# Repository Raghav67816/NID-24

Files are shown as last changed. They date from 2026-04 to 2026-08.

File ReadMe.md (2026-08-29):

# NID-24

NID-24 is a EMG based Humand Device Interface system that allows users to experience unique ways to interact with computers.

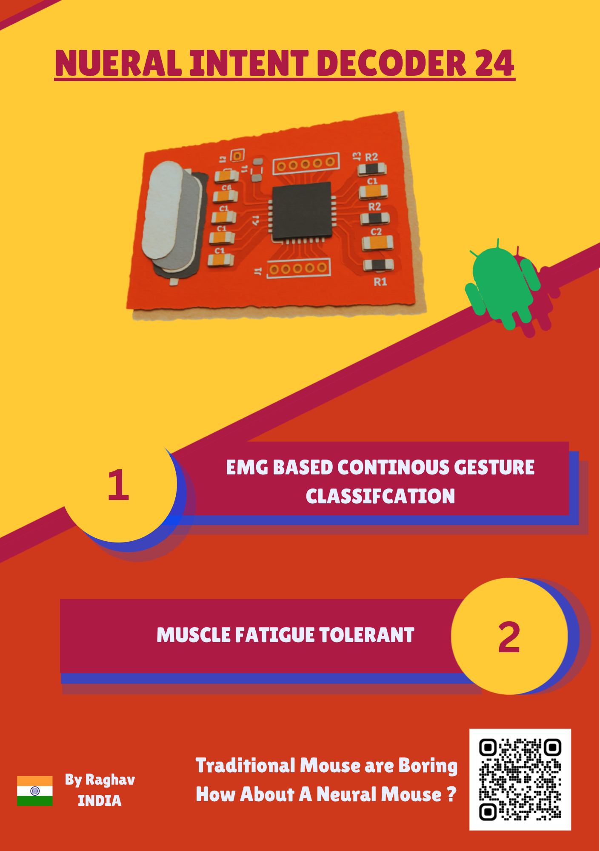
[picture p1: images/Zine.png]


Demo Link - [NID-24 Demo](https://youtu.be/rfTXhZ9J3WQ)

This project allows users to use their hand as mouse. Based on ADS1293 and state-of-the-art software architecture, it continously classifies intent and executes it via bluetooth.

## Why I am building NID-24 ?
Biotech is super awesome, it sits at the intersection of biology and technology. Most of my projects that I made are inspired by sci-fi movies. So, this one is special one from Iron Man 3.

Also, I have some experience in working with EEG, however, I don't have access to a specialised lab, I am building this surface EMG (sEMG) system.

**The second phase of this project will involve finding relevant techniques for making robust EMG system which will can tolerate muscle fatigue and deliver similar performance.**

## Features

 - Analysis Software - Watch and Record Signals In Real Time.

  - ADS1293 Simulator Android App - Don't have the hardware ? Don't worry we have an android app to simulate the hardware readings.

  - Controller Board - Consists of the main MCU Teensy 4.0 for on-board processing, 3 push buttons for menu control, a bluetooth module for data transfer and an OLED 0.96 Inch display

  - ADS1293 based Board - ADS1293 the heart of this project sits at the center of this PCB allowing easy interfacing of chip with the system.

## Directory Structure
- nsys - Analysis Software
- controller_board - The Controller Board
- ads1293_board - The ADS1293 based board
- SignalsSimulator - The Android App (It has it's own readme. Follow instructions to use and install)

## Analysis Software 

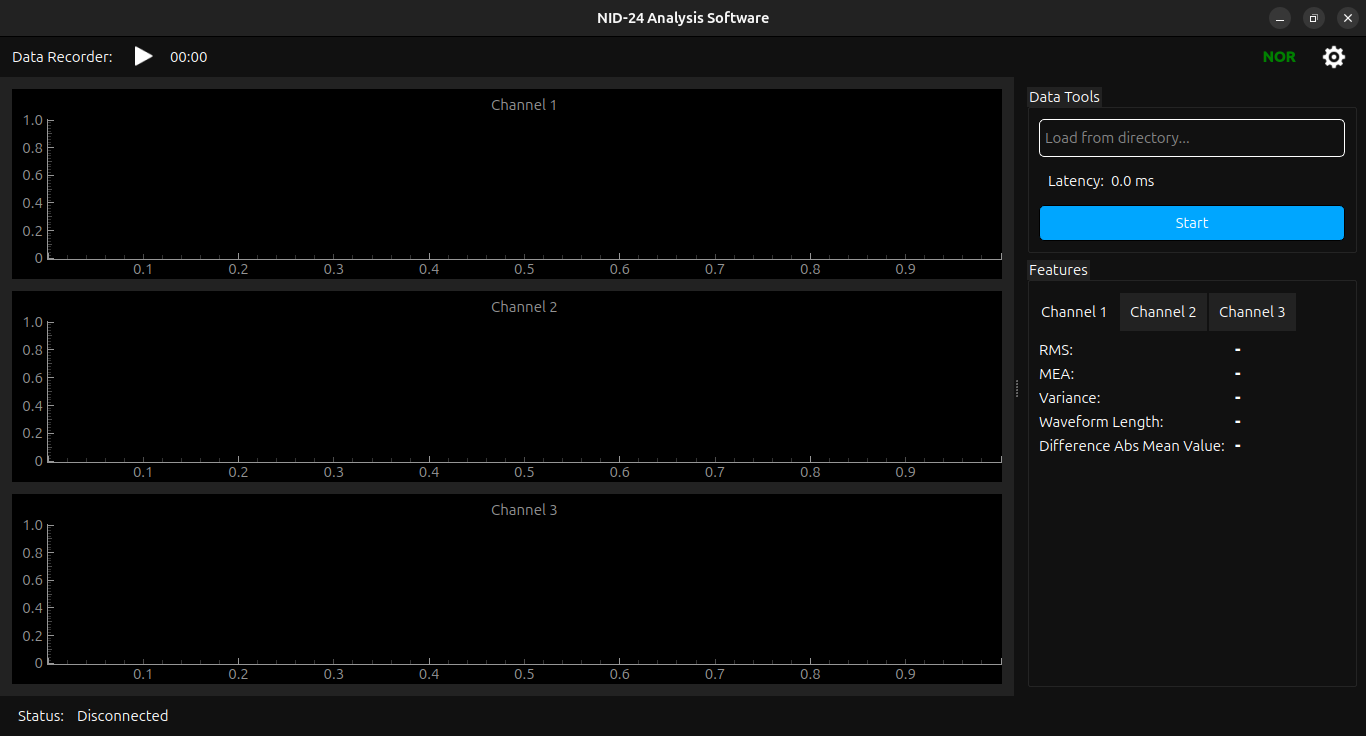
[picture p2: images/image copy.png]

 <!-- Replace this image -->

The Analysis Software allows developers to study the signals to gather information about the signal.

This software visualises all the information from ADS1293.

The features are as follows:
 - 3 Channel EMG (50 ms visual update rate)
 - Latency Meter
 - Data Recorder

## ADS1293 Simulator
Don't worry if you don't have your hardware yet. Just download this app and it will act like our ADS1293 based board.

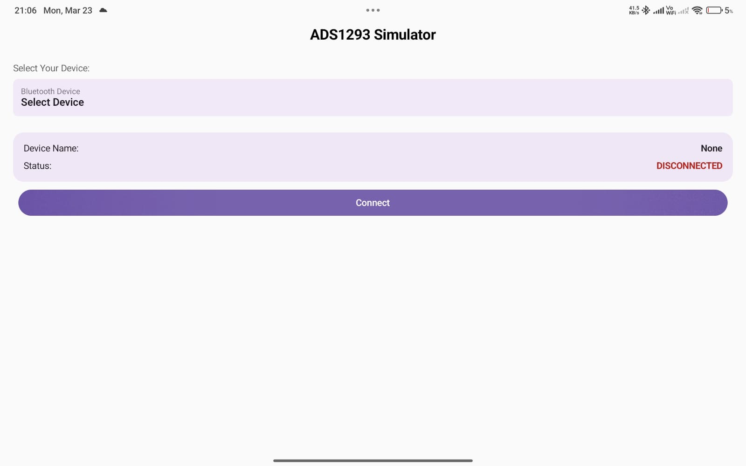
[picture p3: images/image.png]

Currently, it is orientated in Landscape mode, works with potrait too.

This will act like ADS1293 and send data to our computer/analysis software for analysis.

**After using/disconnecting this app. Please make sure to clear it from the background also to avoid residual**

## ADS1293 Based Board (THE HEART)

| Render | PCB |
|---|---|
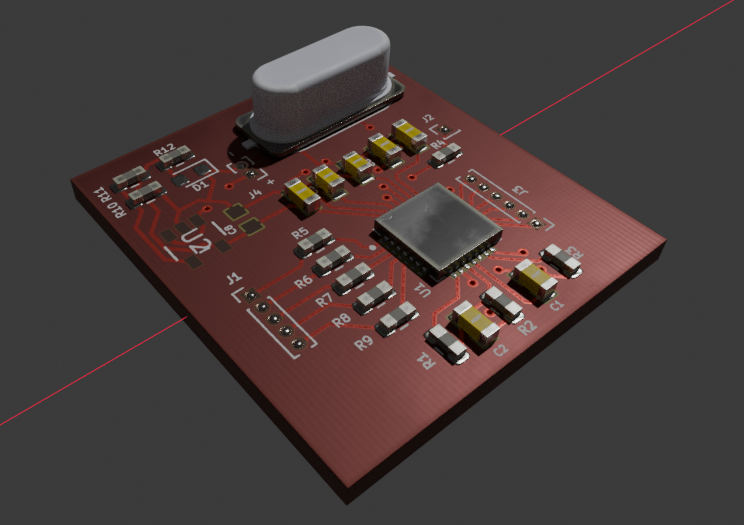
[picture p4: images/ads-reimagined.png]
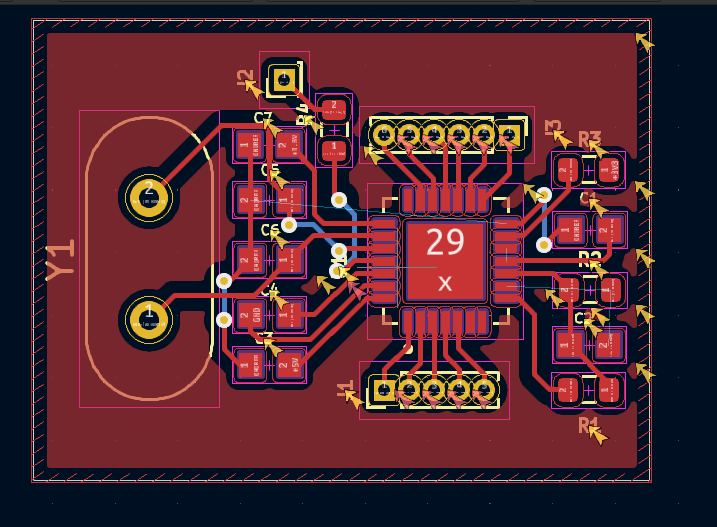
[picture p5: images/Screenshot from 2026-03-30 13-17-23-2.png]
|  |  |

### Features:
 - 24-bit resolution
 - Reduced EMI
 - Saperated analog and digital traces
 - Meets SIMEAN safety standards

This board acquires raw signals from the muscle fibers, the in-built amplifier amplifies the signals and converts AC values to DC values that an be understood by our machines.

We read this data and draw our conclusions

## Controller Board

| Render | PCB |
|---|---|
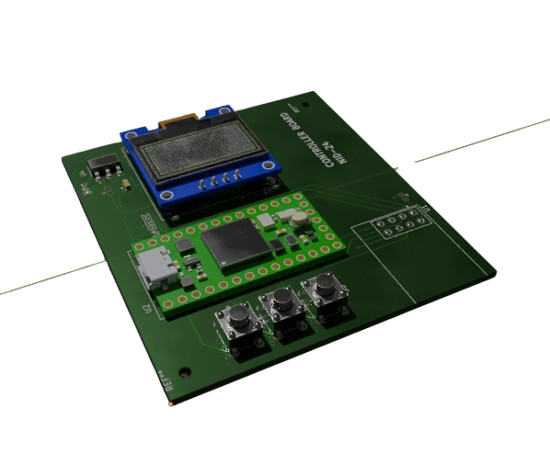
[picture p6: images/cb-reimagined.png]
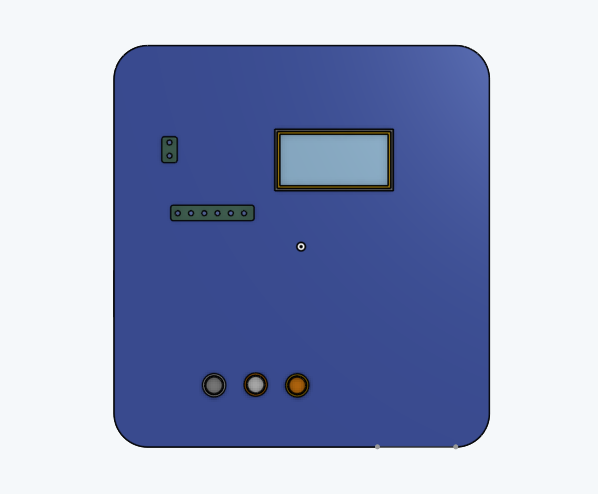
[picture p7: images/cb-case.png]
|  | |

Using simulator is easy you can connect to your PC via system ui bluetooth but we don't have any way to connect out Teensy 4.0 to our PC. So, this PCB has 3 push buttons, 
Teensy 4.0, OLED 0.96 Display and a bluetooth module for data transfer.

Controller Board case Onshape [link here.](https://cad.onshape.com/documents/cf77a823cf461f5b911517e3/w/527c1a40b344ced2cb5cf64d/e/4507412c1ac5528a6c833cb1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)

Features of Case:

1. Smooth curves / No sharp edges
2. No screws required
3. Proper spacing for NRF24L01 module and USB for debugging

## BOM
Please refer to [BOM.csv](https://github.com/Raghav67816/NID-24/blob/9190ff4f1dc71be3fecc9d7e1874cc27b3e914db/BOM%20Final.csv)

## Installation & Setup

 - Clone the repository
   ```bash
   git clone https://github.com/Raghav67816/NID-24.git
   ```

- Install requirements
  ```bash
  pip3 install -r requirements.txt
  ```
  
- Either Setup Real Hardware or Use The Simulator
**WARNING FOR HARDWARE USERS: I am currently unable to disable RLD because of some unknown reasons, their are strong chances that ADS1293 was damaged during assembly. Please measure RLD output before putting electrodes on your body**.

  For hardware, assemble both the boards as defined in the PCB files. And flash the firmware on Controller Board

  Or, safest option is to use the ADS1293 Simulator app

  1. Install the app
  2. Make sure that you enable bluetooth and connect to your PC before starting the app.
  3. Open the app
  4. Select your PC as target device
  5. Click start in NID-24 Analysis Software on your PC
  6. Click Start in your simulator app on mobile

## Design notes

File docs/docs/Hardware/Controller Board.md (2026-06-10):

The Controller Board is respondsible for reporting status of the system i.e:

 - Connection status of MCU and Teensy 4.0
 - Connection of Teensy 4.0 and PC
 - Battery Level of both systems

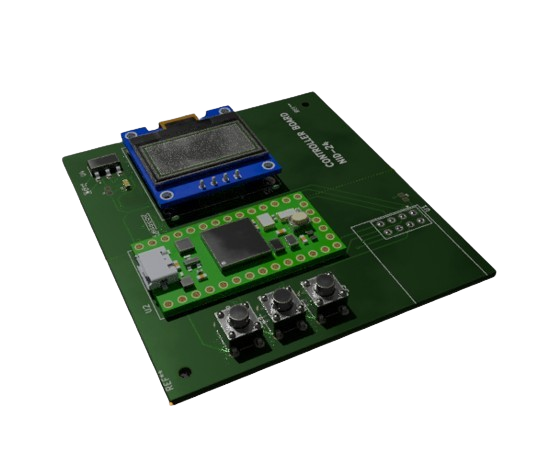
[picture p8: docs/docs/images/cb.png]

<p style="font-size: 14px; text-align: center; font-weight: 100;">Real life board differs from the above render in terms of appearance</p>

!!! warning

    Few processes are pending. Once completed, firmware development will be started and this board will be discussed deeply.

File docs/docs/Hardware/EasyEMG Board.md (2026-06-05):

EasyEMG board is a custom ADS1293 based breakout board configured for 3-channel / 5 lead application. The design of this board strictly follows the guidelines of [datasheet](https://www.ti.com/lit/ds/symlink/ads1293.pdf?ts=1780662406410&ref_url=https%253A%252F%252Fwww.google.com%252F) provided by Texas Instruments.

This board is extremely compact a 20x20 mm board looks like a coin sized PCB. This allows us to develop this project into a consumable project.

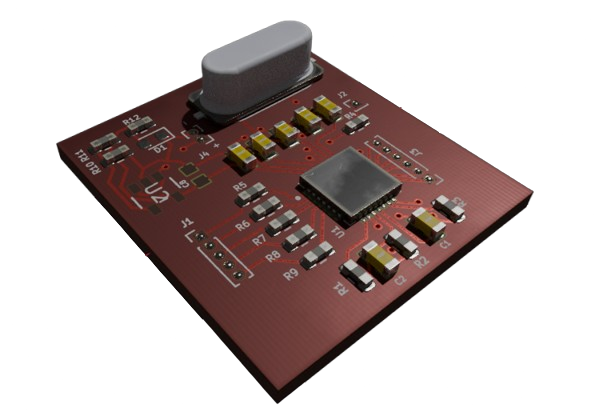
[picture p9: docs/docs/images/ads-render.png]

<p style="font-size: 14px; text-align: center; font-weight: 100;">EasyEMG Board Render. IRL images will shared soon</p>

Features:

 - Super Compact Size (20mm x 20mm)
 - 24-bit ADC resolution
 - Configured for 3 channel / 5 Lead Application
 - Streams data at a frequency of 1 KHz*

The board is being assembled and tested. Actual images will shared soon.
For more information about design please refer to [Page 63](https://www.ti.com/lit/ds/symlink/ads1293.pdf?ts=1780662406410&ref_url=https%253A%252F%252Fwww.google.com%252F) of the datasheet.

PCB files are available here [here](https://github.com/Raghav67816/NID-24/tree/master/ads1293_board/iter2)

!!! warning "Improvements Pending"
    The EasyEMG board requires following improvements:

     - Use of correct LDO. (Currently uses a 5v LDO footprint due to human error)
     - Use of JST connectors instead of pin headers.

**FIRMWARE WILL BE DISCUSSED SOON**

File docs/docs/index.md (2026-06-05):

## Overview

Weclome to NID-24 project. We are building a muscle fatigue tolerant EMG system primary aimed to developing exciting **human-computer-interfaces**. Our goal is to build a stable pipeline for sEMG signals acquisition. The core pipeline will allow development of diverse applications with ease.

The project is divided into 3 main parts which can studied deeply in the upcoming sections.

 - Hardware: Includes custom ADS1293 based breakout board.
 - Software: Includes development tools.
 - CAD: Includes plans on reducing size of the system to turn this into a wearable and more accessible product.

## Features

 - Modular Software Systems
 - Easy To Get Started No Setup Required
 - Extensive Developer Tools
 - Coin Sized PCBs
 - 100% Open-Source

## General Architecture

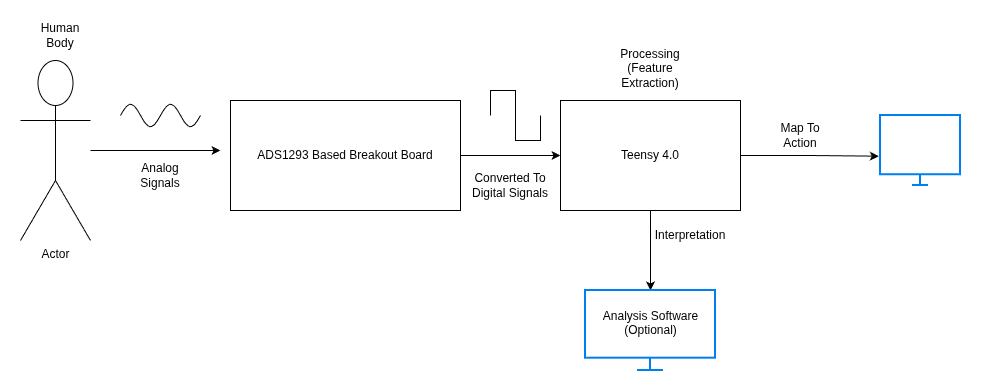
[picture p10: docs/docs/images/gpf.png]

<p style="font-size: 14px; text-align: center; font-weight: 100;">A quick representation of general logic of the system</p>

Electrodes are attached to the human body, ADS1293 receives these analog signals and converts them into digital signals. These digital signals are processed by Teensy 4.0, the board extracts required features and feeds it to the AI model for action mapping. The output is shared to the PC over bluetooth acting like a mouse.

!!! warning ""
    The inital aim of the project is aimed at the application of this system into a non-traditional mouse. However, in the curent phase pointer movement is not supported.

## Development Roadmap

Phase 1:

 - [x] Analysis Software Development (Stable)
 - [x] Modification of ECG Cable
 - [x] Verification of Power Rails In ADS1293 Breakout Board
 - [ ] Controller Board Firmware
 - [ ] ADS1293 Configuration
 - [ ] Dataset Preparation
 - [ ] Data Labeling
 - [ ] Model Training

Phase 2:

 - [ ] Development of Smaller MCU
 - [ ] Integration of IMU for 2D movement of mouse pointer
 - [ ] Fatigue tolerance
 - [ ] Wearable Design

## Contributing

Contributes are highly welcomed. If you want to get involved please open issues in the GitHub repos, or email me at [kumaraghav079@gmail.com](mailto:kumaraghav079@gmail.com)

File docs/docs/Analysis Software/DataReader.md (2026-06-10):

The data enters into the application from this point. Data reader manages two internal ring buffers **visualisation buffer** and **main buffer**. The main buffer holds **1000** values while visualisation buffer holds **100** data packets.

The visualisation buffer is derived from the main buffer. The buffer holds latest values from the main buffer.

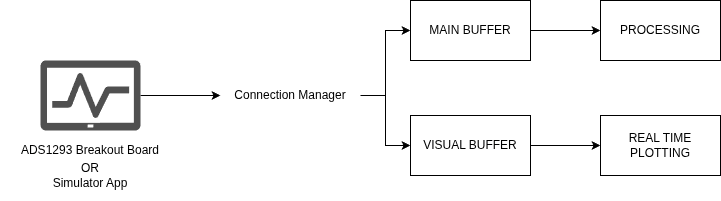
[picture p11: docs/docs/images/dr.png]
DataFlow


The main buffer is not modified at any stage of processing, each component of the application process it in it's own way without modifying the original buffer.

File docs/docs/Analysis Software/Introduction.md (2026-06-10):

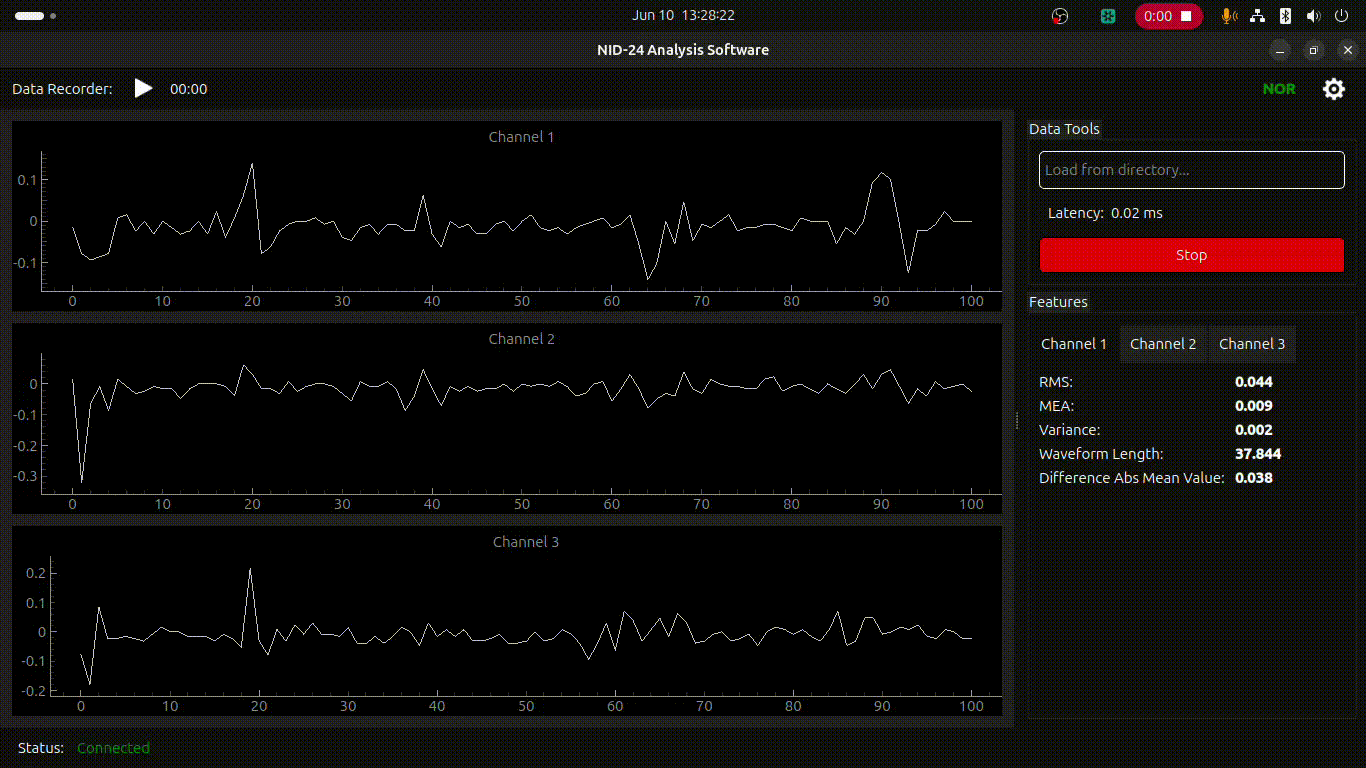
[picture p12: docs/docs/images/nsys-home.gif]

<p style="font-size: 14px; text-align: center; font-weight: 100;">Analysis Software</p>

Analysis software allows you to observe sEMG signals in real-time. You can create your own datasets using the utility provided. The software is based on modular components allowing you to modify codebase easily. This development pattern allows fault-tolerant system.

## Features

 - Visualise signals in real-time.
 - Create your own datasets.
 - Record observations.
 - Plug and Play software.
 - Modular and fault tolerant architecture.
 - Observe signal features change in real time.

## Supported Platforms 



## Development Stack

      

## Installation

Installation is simple and straightforward follow the steps below to install the application.

1. Clone the repository

```bash
git clone https://github.com/Raghav67816/NID-24.git
```

2. Enter into the cloned directory.

```bash
cd NID-24/
```

!!! info
    Please install Python3 before continuing.

3. Create a virtualenv and install requirements.

```bash
pip3 install virtualenv
virtualenv env
source env/bin/activate

pip3 install -r requirements.txt
```

4. Run application

```bash
sudo ./env/bin/python3 app.py
```

!!! info
    The application requires to interact with **rfcomm** utility of Linux system. Thus, root permissions must be provided in the way above.

## Troubleshooting

### 1. Controller Board cannot connect to PC

The application requires **rfcomm** utility to enable devices to connect. However, if you have **Bluez ≥ 5.4** this will not work because newer version of Bluez have dropped support for rfcomm. However, rfcomm is very stable and completely satisfies the requirements of analysis software.

To fix this, run bluetooth service in **compatibility mode**

 - Open the bluetooth service file (for systemd)

```bash
sudo nano /usr/lib/systemd/system/bluetooth.service
```

 - Locate the following line

```bash
[Service]
Type=dbus
BusName=org.bluez
ExecStart=/usr/libexec/bluetooth/bluetoothd # this one
NotifyAccess=main
#WatchdogSec=10
Restart=on-failure
CapabilityBoundingSet=CAP_NET_ADMIN CAP_NET_BIND_SERVICE
LimitNPROC=1
```

 - Add compatibility flag

```bash
[Service]
Type=dbus
BusName=org.bluez
ExecStart=/usr/libexec/bluetooth/bluetoothd --compat  # like this
NotifyAccess=main
#WatchdogSec=10
Restart=on-failure
CapabilityBoundingSet=CAP_NET_ADMIN CAP_NET_BIND_SERVICE
LimitNPROC=1
```

 - Restart bluetooth service and daemon

```bash
sudo systemctl restart bluetooth.service
sudo systemctl daemon-reload
```

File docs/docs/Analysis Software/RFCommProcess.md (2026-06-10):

RFCommProcess class is responsible for managing the rfcomm process and it's state. It starts the rfcomm process and observes it's state. This class inherits from **QProcess** and runs the rfcomm process by executing:

```bash
sudo rfcomm listen hci0
```

This also adds an SDP profile internally. When a device connects or disconnects the state is emitted by the class.

## Signals

`com_finished`: Emitted when process is finished. The signal returns **int exit_code** and **str message**

!!! info
    The class contains a **cleanup()** function. If you are making your own utilities with rfcomm make sure that you call this function on application exit.

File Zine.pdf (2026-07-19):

# NUERAL INTENT DECODER 24

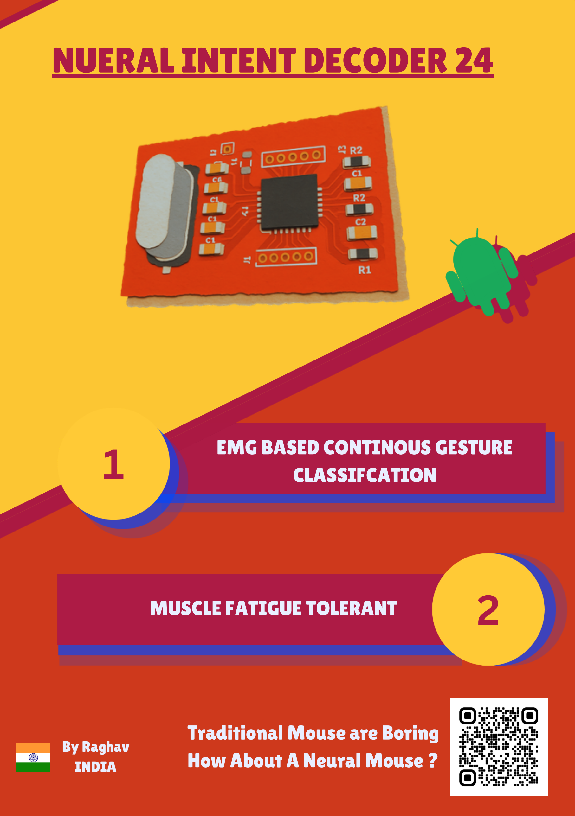
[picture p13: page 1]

1

EMG BASED CONTINOUS GESTURE CLASSIFCATION

MUSCLE FATIGUE TOLERANT | 2

Traditional Mouse are Boring How About A Neural Mouse ?

By Raghav
INDIA

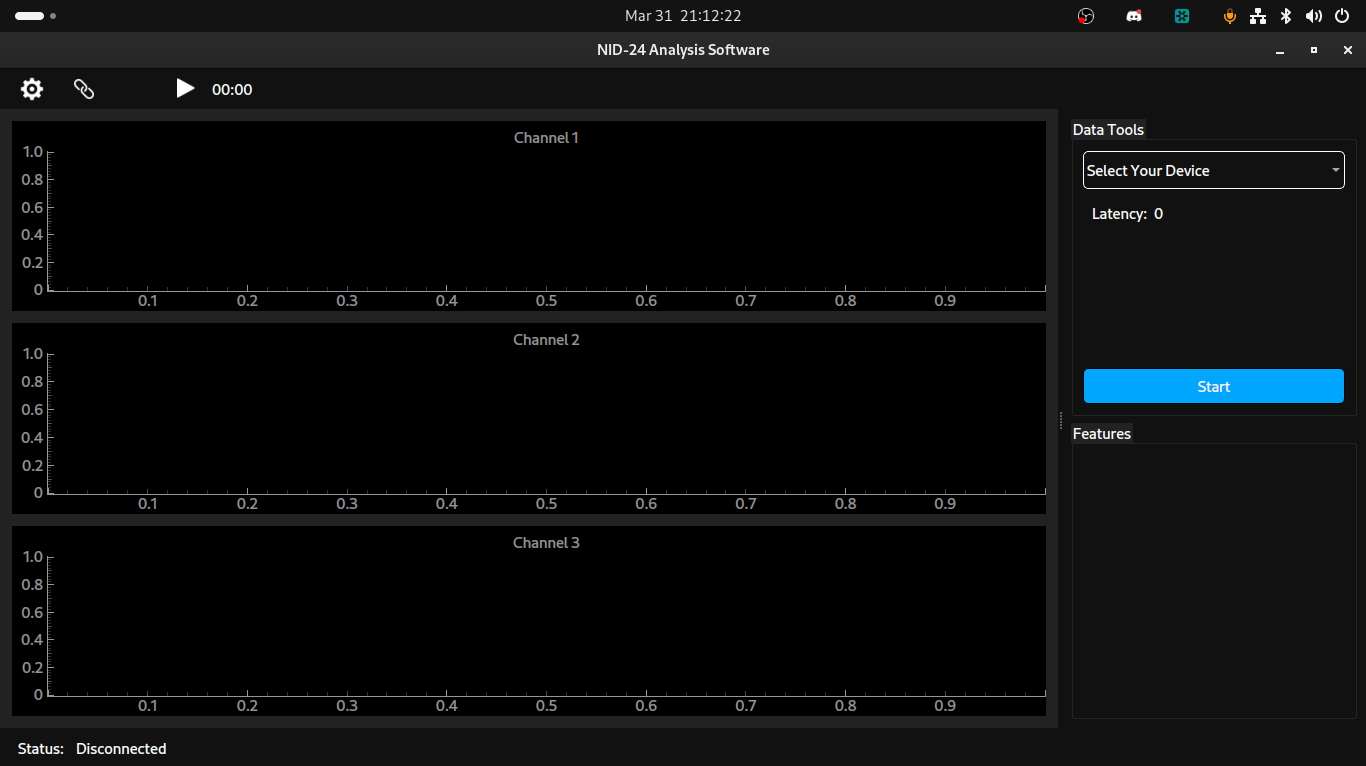
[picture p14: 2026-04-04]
images/Screenshot from 2026-03-31 21-12-26.png

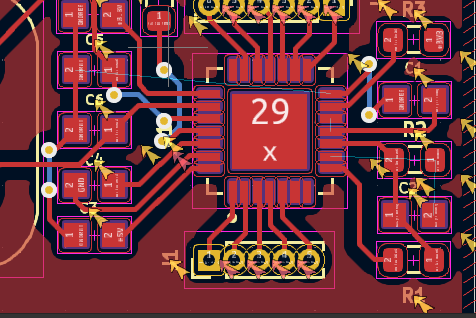
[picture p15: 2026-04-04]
images/Screenshot from 2026-03-30 13-15-55.png

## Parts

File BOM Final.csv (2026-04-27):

S. No | Name | Value | Unit Price | Qty | Total | Link | Remarks
1 | ADS1293 | - | $12.00 | 1 | 12 | https://www.lcsc.com/product-detail/C181260.html?s_z=n_q_ads1293 | -
2 | Crystal 4.096 HZ | 4.096 Hz | $0.01 | 5 | 0.05 | https://www.lcsc.com/product-detail/C2842312.html?s_z=n_q_HC-49S | Minimum 5 qty have to be ordered.
3 | Resistors 0603 SMD | 100K Ohms | $0.14 | 1 | 0.14 | https://www.lcsc.com/product-detail/C70047.html?s_z=n_q_Resistor%2520SMD%25200603
4 | Resistor 0603 SMD | 1M Ohms | $0.16 | 1 | 0.16 | https://www.lcsc.com/product-detail/C105578.html?s_z=n_q_Resistor%2520SMD%25200603%25201M%2520ohms
5 | Resistor 0603 SMD | 10K Ohms | $0.15 | 1 | 0.15 | https://www.lcsc.com/product-detail/C105578.html?s_z=n_q_Resistor%2520SMD%25200603%25201M%2520ohms
6 | Resistor 0603 SMD | 220 Ohms | $0.10 | 1 | 0.1 | Local Shop
7 | LED Green |  | $0.73 | 1 | 0.73 | https://www.lcsc.com/product-detail/C2994781.html?s_z=n_q_LED%2520Green%25200603
8 | Capacitors SMD | 1uF | $0.32 | 1 | 0.32 | https://www.lcsc.com/product-detail/C29936.html?s_z=n_q_Capacitor%25200603%25201uF
9 | Capacitors SMD | 1.5nF | $0.28 | 1 | 0.28 | https://www.lcsc.com/product-detail/C96090.html?s_z=n_q_Capacitor%25200603%25201500%2520pF
10 | Capacitors SMD | 22pF | $0.36 | 1 | 0.36 | https://www.lcsc.com/product-detail/C1653.html?s_z=n_q_Capacitor%25200603%252022pF
11 | Capacitor SMD | 0.1 uF | $0.31 | 1 | 0.31 | https://www.lcsc.com/product-detail/C14663.html?s_z=n_q_Capacitor%25200603%25200.1uF
12 | MaxLinear SPX5205M5-L-5-0/TR |  | $0.98 | 1 | 0.98 | https://www.lcsc.com/product-detail/C6865.html?s_z=n_q_SPX5205M5-L-5-0%252FTR
13 | TLV1117LV33DCYR |  | $1.26 | 1 | 1.26 | https://www.lcsc.com/product-detail/C15578.html?s_z=n_q_TLV1117LV33DCYR
14 | CUI TS02-66-55-BK-100-LCR-D |  | $0.06 | 3 | 0.18 | https://www.lcsc.com/product-detail/C4364472.html?s_z=n_q_TS02-66-55-BK-100-LCR-D
15 | NRF24L01 Module |  | $0.82 | 1 | 0.82 | https://robu.in/product/nrf24l01-wireless-module-mini-power-enhancement-2-4g-wireless-transceiver-module
 | OLED Display 0.96 Inch |  | $1.81 | 1 | 1.81 | https://robu.in/product/4pin-oled-display-module-blue-color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
 | Teensy 4.0 |  | $26.53 | 1 | 26.53 | https://robocraze.com/products/teensy-4-0-development-board
 | Jumper Cables |  | $0.42 | 1 | 0.42 | https://robu.in/product/20cm-dupont-wire-color-jumper-cable-2-54mm-1p-1p-female-female-40pcs
 | Adafruit sEMG Electrodes |  | $8.10 | 1 | 8.1 | https://robu.in/product/adafruit-accessories-muscle-sensor-surface-emg-electrodes-h124sg-covidien-pack-of-6
 | Snap Electrodes |  | $8.75 | 1 | 8.75 | https://www.sparkfun.com/sensor-cable-electrode-pads-3-connector.html
 | Pin Headers |  | $1.00 | 1 | 1 |  | Can't Find Specific Ones. Need to cut use larger pieces and adjust accordingly
 | TPSP6201EM5-L-3-3 |  | $0.57 | 1 | 0.57 | https://www.lcsc.com/product-detail/C3021092.html?s_z=n_q_SP6201EM5
 |  |  |  | GRAND TOTAL | $65.02

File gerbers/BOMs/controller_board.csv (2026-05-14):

Reference | Qty | Value | DNP | Exclude from BOM | Exclude from Board | Footprint | Datasheet
C1 | 1 | 1uF |  |  |  | C0603C220J5GACTU:CAPC1608X87N
C2 | 1 | 1uF |  |  |  | C0603C223J5RACTU:CAPC1608X87N
C3 | 1 | 10uF |  |  |  | C0603C220J5GACTU:CAPC1608X87N
D1 | 1 | LED |  |  |  | LED_SMD:LED_0603_1608Metric_Pad1.05x0.95mm_HandSolder | ~
J1 | 1 | Conn_01x02_Pin |  |  |  | Connector_PinHeader_2.54mm:PinHeader_1x02_P2.54mm_Vertical | ~
J2 | 1 | GPIO |  |  |  | Connector_PinHeader_2.54mm:PinHeader_1x06_P2.54mm_Vertical | ~
R1 | 1 | 220 Ohms |  |  |  | Resistor_SMD:R_0603_1608Metric_Pad0.98x0.95mm_HandSolder | ~
S1,S2,S3 | 3 | TS02-66-55-BK-100-LCR-D |  |  |  | TS02_66_55_BK_100_LCR_D:SW_TS02-66-55-BK-100-LCR-D
U1 | 1 | NRF24L01_Breakout |  |  |  | RF_Module:nRF24L01_Breakout | http://www.nordicsemi.com/eng/content/download/2730/34105/file/nRF24L01_Product_Specification_v2_0.pdf
U2 | 1 | DEV-15583 |  |  |  | DEV-15583:MODULE_DEV-15583
U3 | 1 | DM-OLED096-636 |  |  |  | DM-OLED096-636:MODULE_DM-OLED096-636
U4 | 1 | TLV1117LV33DCYR |  |  |  | TLV1117LV33DCYR:VREG_TLV1117LV33DCYR

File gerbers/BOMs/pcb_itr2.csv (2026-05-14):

Reference | Qty | Value | DNP | Exclude from BOM | Exclude from Board | Footprint | Datasheet
C1,C4,C8 | 3 | 1uF |  |  |  | C0603C223J5RACTU:CAPC1608X87N
C2 | 1 | 1.5 nF |  |  |  | C0603C223J5RACTU:CAPC1608X87N
C3 | 1 | 0.1uF |  |  |  | C0603C223J5RACTU:CAPC1608X87N
C5,C6 | 2 | 22pF |  |  |  | C0603C223J5RACTU:CAPC1608X87N
C7 | 1 | 0.1 uF |  |  |  | C0603C223J5RACTU:CAPC1608X87N
D1 | 1 | LED |  |  |  | LED_SMD:LED_0603_1608Metric | ~
J1 | 1 | Conn_01x05_Pin |  |  |  | Connector_PinHeader_2.54mm:PinHeader_1x05_P2.54mm_Vertical | ~
J2 | 1 | RSTB_J |  |  |  | Connector_PinHeader_1.00mm:PinHeader_1x01_P1.00mm_Vertical | ~
J3 | 1 | Breakout Pins |  |  |  | Connector_PinHeader_2.54mm:PinHeader_1x06_P2.54mm_Vertical | ~
J4 | 1 | Power Input |  |  |  | Connector_PinHeader_2.54mm:PinHeader_1x02_P2.54mm_Vertical | ~
R1 | 1 | 100K |  |  |  | Resistor_SMD:R_0603_1608Metric | ~
R2 | 1 | 1M Ohms |  |  |  | Resistor_SMD:R_0603_1608Metric | ~
R3 | 1 | 1M Ohm |  |  |  | Resistor_SMD:R_0603_1608Metric | ~
R4 | 1 | 1 M Ohms |  |  |  | Resistor_SMD:R_0603_1608Metric | ~
R5,R6,R7,R8,R9 | 5 | 10K |  |  |  | Resistor_SMD:R_0603_1608Metric | ~
R10 | 1 | 22K Ohm |  |  |  | Resistor_SMD:R_0603_1608Metric | ~
R11 | 1 | 12K Ohm |  |  |  | Resistor_SMD:R_0603_1608Metric | ~
R12 | 1 | 220 Ohms |  |  |  | Resistor_SMD:R_0603_1608Metric | ~
U1 | 1 | ADS1293CISQ/NOPB |  |  |  | ADS1293CISQ_NOPB:QFN50P500X500X80-29N | https://www.ti.com/lit/gpn/ads1293
U2 | 1 | SPX5205M5-L-5-0/TR |  |  |  | SP6201EM5 | SPX5205M5-L-5-0/TR
Y1 | 1 | 4.096 MHz |  |  |  | Crystal:Crystal_HC18-U_Vertical | ~

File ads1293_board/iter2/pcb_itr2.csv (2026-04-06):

# | Reference | Qty | Value | Footprint | DNP
1 | C1, C4, C8 | 3 | 1uF | C0603C223J5RACTU:CAPC1608X87N
2 | C2 | 1 | 1.5 nF | C0603C223J5RACTU:CAPC1608X87N
3 | C3 | 1 | 0.1uF | C0603C223J5RACTU:CAPC1608X87N
4 | C5, C6 | 2 | 22pF | C0603C223J5RACTU:CAPC1608X87N
5 | C7 | 1 | 0.1 uF | C0603C223J5RACTU:CAPC1608X87N
6 | D1 | 1 | LED | LED_SMD:LED_0603_1608Metric
7 | J1 | 1 | Conn_01x05_Pin | Connector_PinHeader_1.00mm:PinHeader_1x05_P1.00mm_Vertical
8 | J2 | 1 | RSTB_J | Connector_PinHeader_1.00mm:PinHeader_1x01_P1.00mm_Vertical
9 | J3 | 1 | Breakout Pins | Connector_PinHeader_1.00mm:PinHeader_1x06_P1.00mm_Vertical
10 | J4 | 1 | Power Input | Connector_PinHeader_1.00mm:PinHeader_1x02_P1.00mm_Vertical
11 | R1 | 1 | 100K | Resistor_SMD:R_0603_1608Metric
12 | R2 | 1 | 1M Ohms | Resistor_SMD:R_0603_1608Metric
13 | R3 | 1 | 1M Ohm | Resistor_SMD:R_0603_1608Metric
14 | R4 | 1 | 1 M Ohms | Resistor_SMD:R_0603_1608Metric
15 | R5, R6, R7, R8, R9 | 5 | 10K | Resistor_SMD:R_0603_1608Metric
16 | R10 | 1 | 22K Ohm | Resistor_SMD:R_0603_1608Metric
17 | R11 | 1 | 12K Ohm | Resistor_SMD:R_0603_1608Metric
18 | R12 | 1 | 220 Ohms | Resistor_SMD:R_0603_1608Metric
19 | U1 | 1 | ADS1293CISQ/NOPB | ADS1293CISQ_NOPB:QFN50P500X500X80-29N
20 | U2 | 1 | SPX5205M5-L-5-0/TR | SP6201EM5
21 | Y1 | 1 | 4.096 MHz | Crystal:Crystal_HC18-U_Vertical

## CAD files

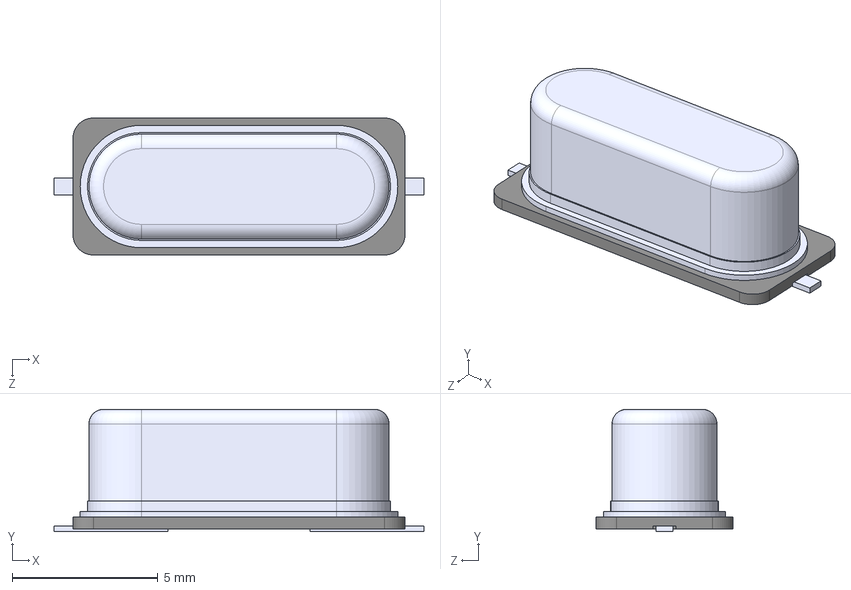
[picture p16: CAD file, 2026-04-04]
ads1293_board/ABLS_4_096MHZ_L4Q_T/ABLS-4.096MHZ-L4Q-T.step
12.7 x 4.20 x 4.70 mm

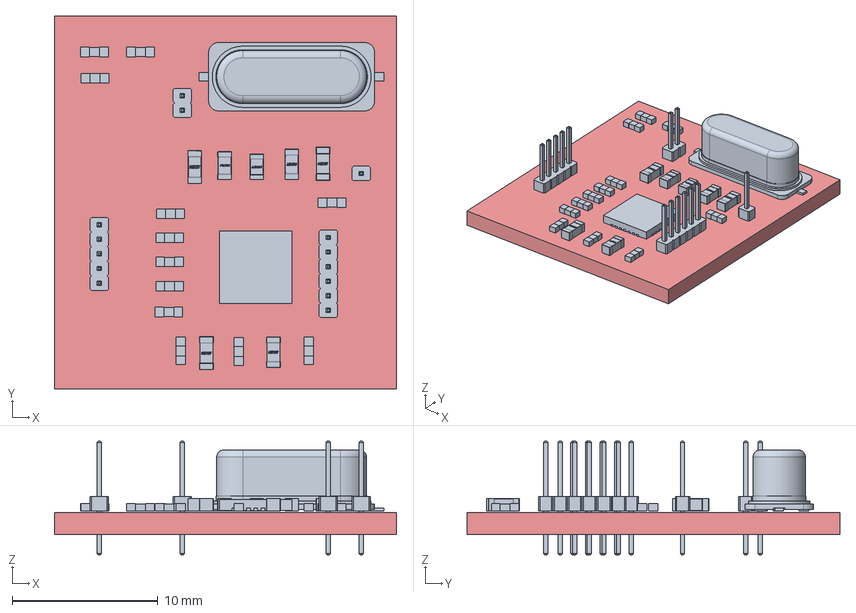
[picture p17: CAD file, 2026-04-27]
ads1293_board/ads1293_board.step
23.5 x 25.6 x 7.80 mm
CCS_CCSTD_0603_L1.75W0.95T0.87B0.35 x 7
PinHeader_1x06_P1.00mm_Vertical
YAG_R0201_YAG x 12
PinHeader_1x05_P1.00mm_Vertical
ABLS-4.096MHZ-L4Q-T
PinHeader_1x01_P1.00mm_Vertical
PinHeader_1x02_P1.00mm_Vertical
ADS1293CISQ_NOPB
pcb_itr2_PCB

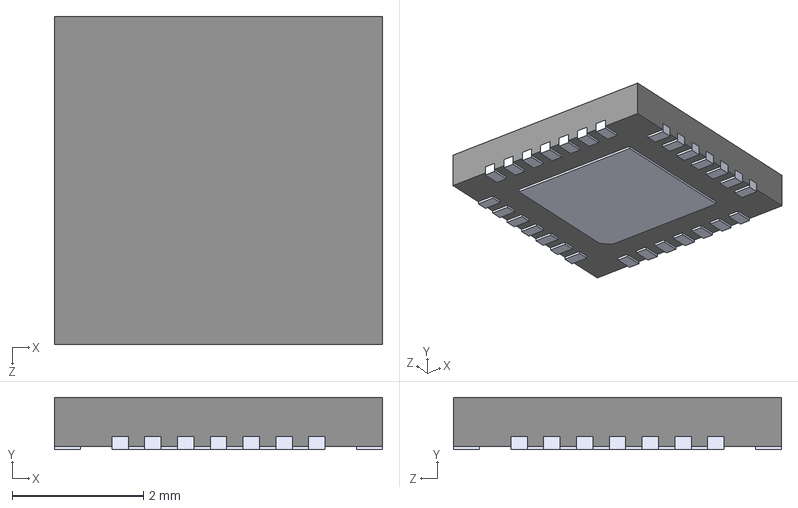
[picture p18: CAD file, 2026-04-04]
ads1293_board/ADS1293CISQ_NOPB/ADS1293CISQ_NOPB.step
5.00 x 0.8 x 5.00 mm

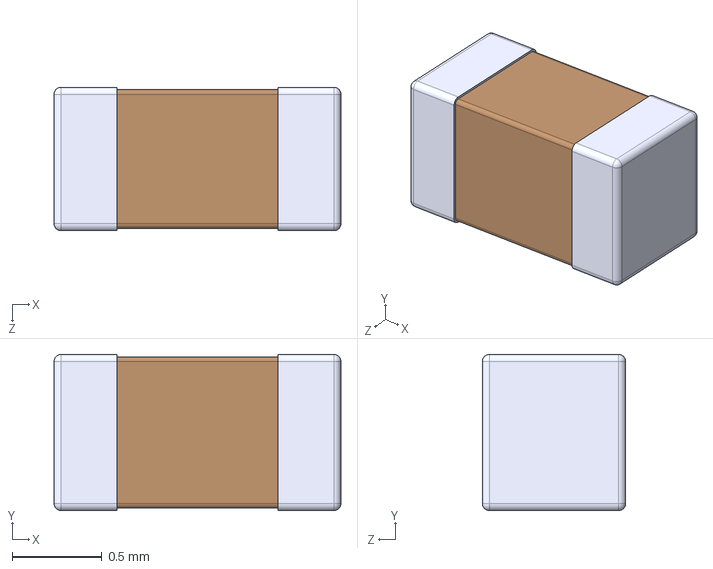
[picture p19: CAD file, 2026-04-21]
ads1293_board/C0603C220J5GACTU/C0603C223J5RACTU.step
1.60 x 0.87 x 0.8 mm

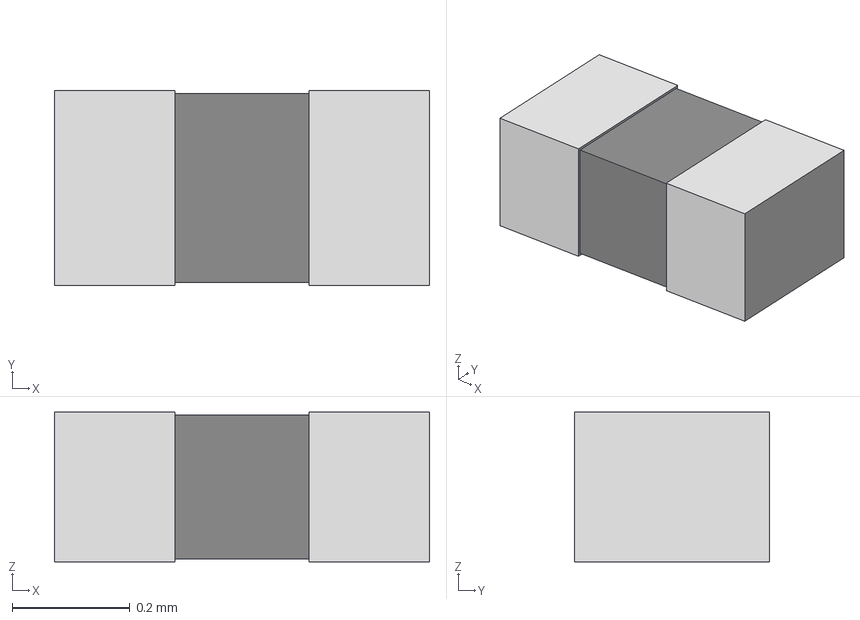
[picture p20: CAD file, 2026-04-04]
ads1293_board/RC0201FR_0710KL/YAG_R0201_YAG.step
0.636 x 0.33 x 0.254 mm

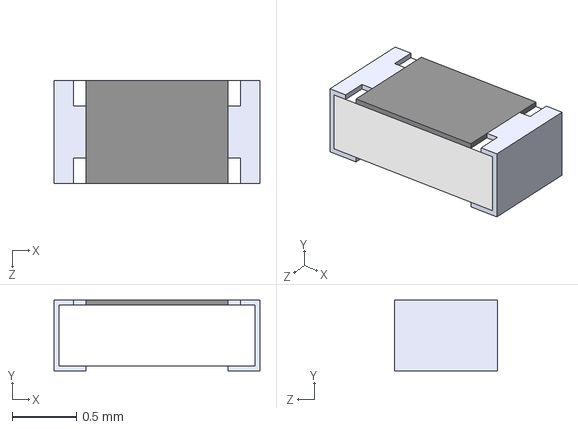
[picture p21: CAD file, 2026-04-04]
ads1293_board/RC0603JR_070RL/RC0603JR-070RL.step
1.60 x 0.55 x 0.8 mm

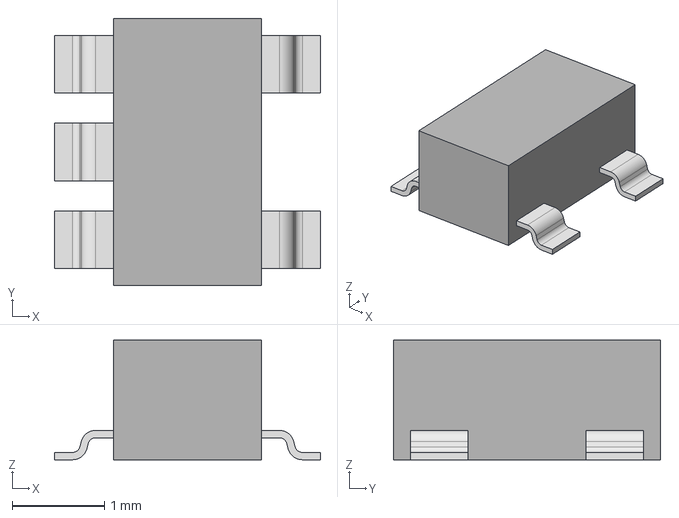
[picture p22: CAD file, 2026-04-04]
ads1293_board/SPX5205M5_L_5_0_TR/SP6201EM5.step
2.88 x 2.90 x 1.29 mm

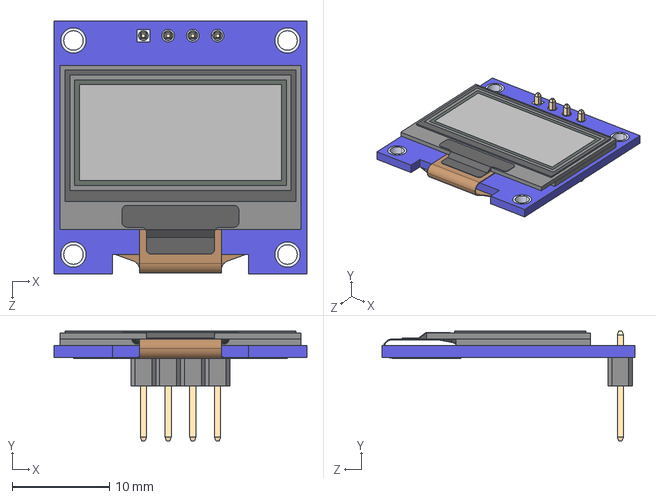
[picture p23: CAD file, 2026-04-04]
controller_board/DM-OLED096-636--3DModel-STEP-56544.STEP
26.0 x 11.3 x 26.0 mm
DM-OLED096-636_Module
DM-OLED096-636_Panel

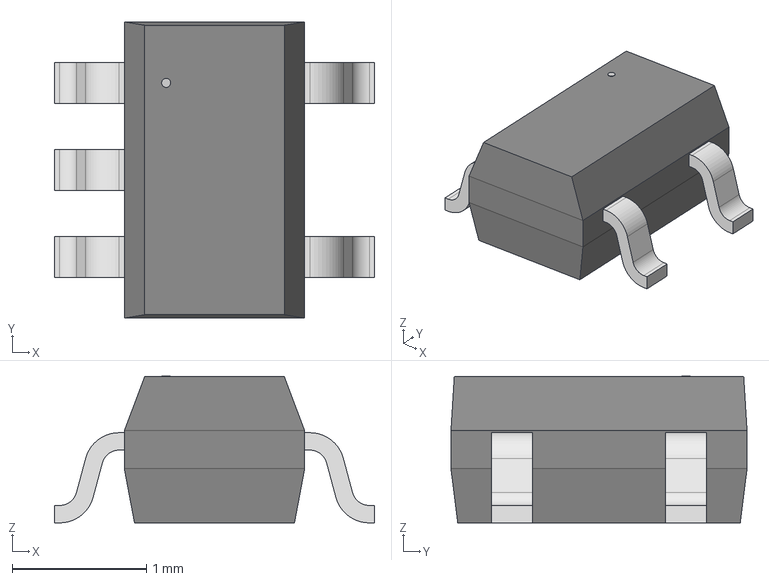
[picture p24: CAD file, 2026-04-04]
controller_board/MIC5365_3_3YC5_TR/SC-70_C5_MCH.step
2.39 x 2.21 x 1.09 mm

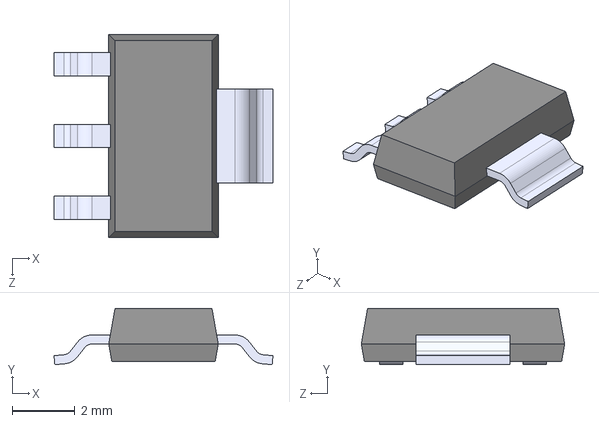
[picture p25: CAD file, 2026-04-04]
controller_board/TLV1117LV33DCYR/TLV1117LV33DCYR.step
7.00 x 1.80 x 6.50 mm

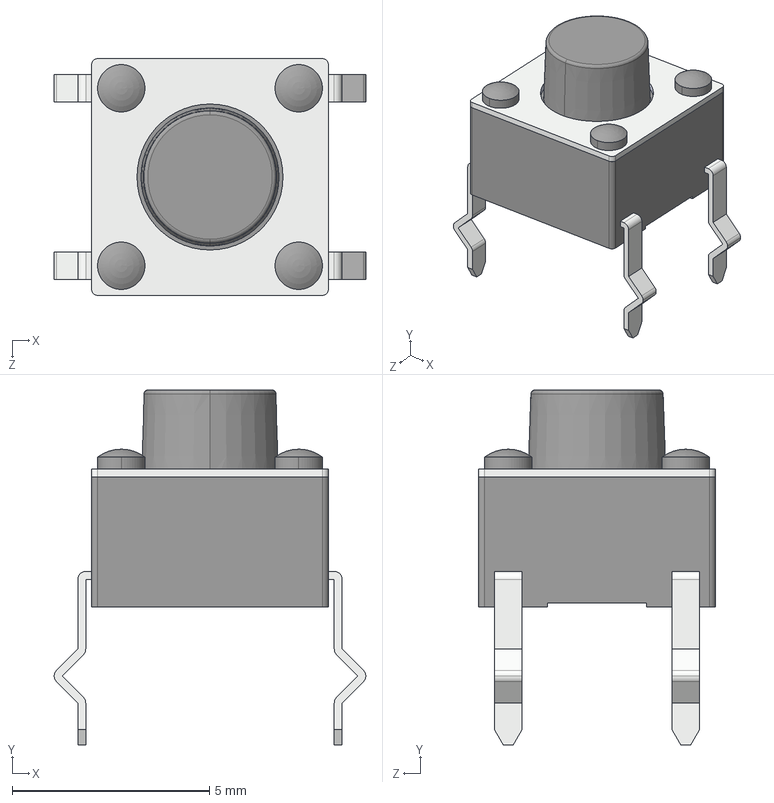
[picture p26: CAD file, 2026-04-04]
controller_board/TS02_66_55_BK_100_LCR_D/TS02-66-55-BK-100-LCR-D.step
7.90 x 9.00 x 6.00 mm

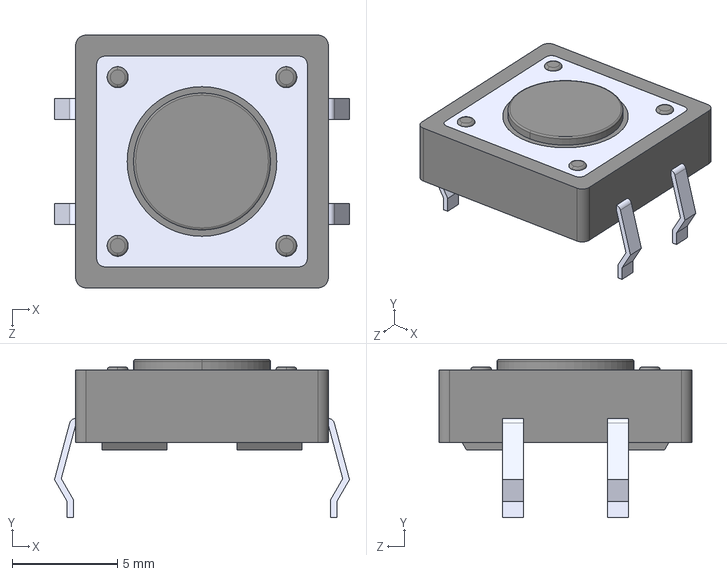
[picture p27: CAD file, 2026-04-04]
controller_board/VS-1213-67-160GF/VS-1213-67-160GF.step
14.0 x 7.50 x 12.0 mm

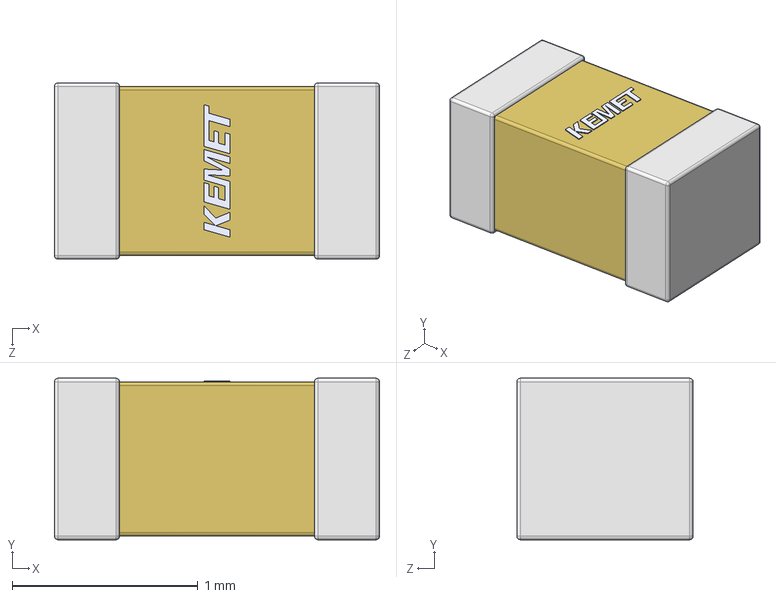
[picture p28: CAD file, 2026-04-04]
ads1293_board/C0603C220J5GACTU/CCS_CCSTD_0603_L1.75W0.95T0.87B0.35.step
1.75 x 0.87 x 0.95 mm

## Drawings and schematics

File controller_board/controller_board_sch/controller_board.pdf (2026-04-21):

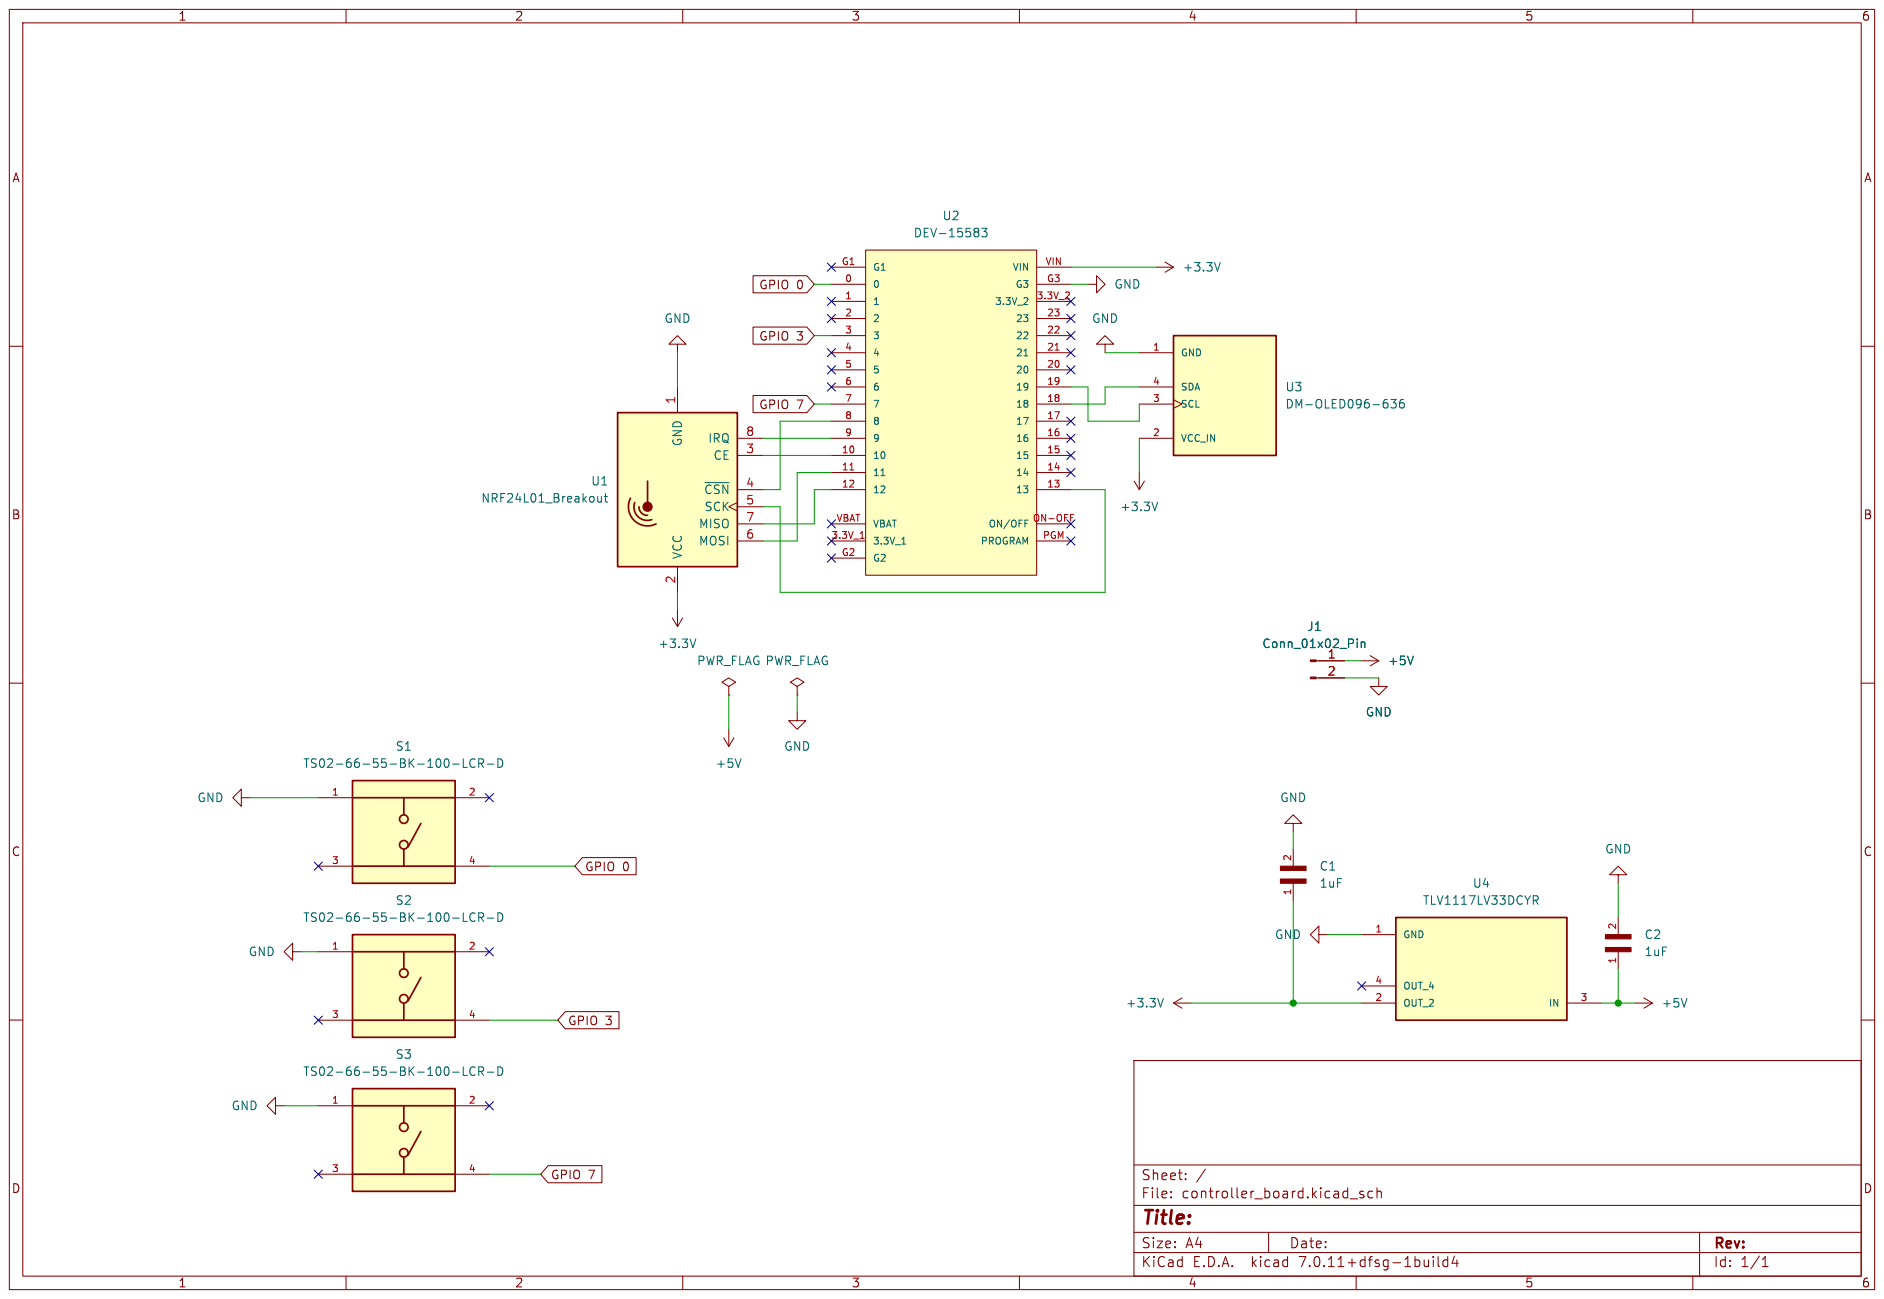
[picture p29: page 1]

2 CE 3 ~{CSN} 4 SCK 5 MOSI 6 MISO 7

Id: 1/1 Title: File: controller_board.kicad_sch Sheet: / +3.3V

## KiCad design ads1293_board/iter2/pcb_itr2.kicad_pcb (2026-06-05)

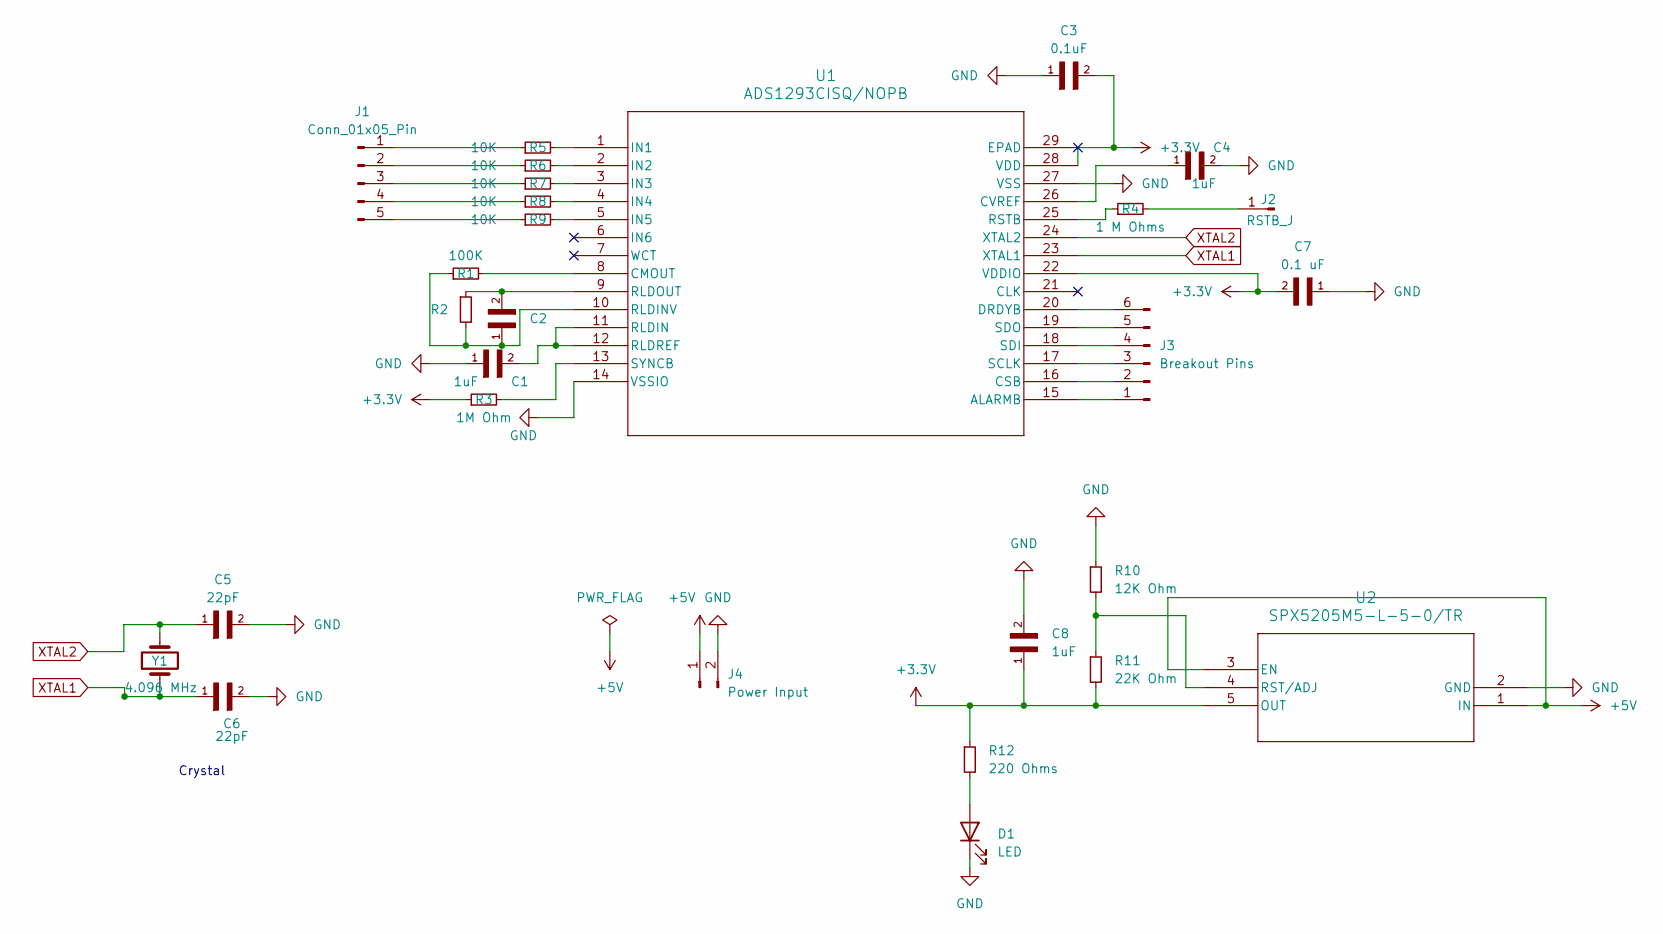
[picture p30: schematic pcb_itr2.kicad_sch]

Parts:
C1, C4, C8: 1uF; CAPC1608X87N
C2: 1.5 nF; CAPC1608X87N
C3: 0.1uF; CAPC1608X87N
C5, C6: 22pF; CAPC1608X87N
C7: 0.1 uF; CAPC1608X87N
D1: LED; LED_0603_1608Metric
J1: Conn_01x05_Pin; PinHeader_1x05_P2.54mm_Vertical
J2: RSTB_J; PinHeader_1x01_P1.00mm_Vertical
J3: Breakout Pins; PinHeader_1x06_P2.54mm_Vertical
J4: Power Input; PinHeader_1x02_P2.54mm_Vertical
R1: 100K; R_0603_1608Metric
R2: 1M Ohms; R_0603_1608Metric
R3: 1M Ohm; R_0603_1608Metric
R4: 1 M Ohms; R_0603_1608Metric
R5, R6, R7, R8, R9: 10K; R_0603_1608Metric
R10: 12K Ohm; R_0603_1608Metric
R11: 22K Ohm; R_0603_1608Metric
R12: 220 Ohms; R_0603_1608Metric
U1: ADS1293CISQ/NOPB; QFN50P500X500X80-29N
U2: SPX5205M5-L-5-0/TR; SP6201EM5
Y1: 4.096 MHz; Crystal_HC18-U_Vertical

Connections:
+3.3V: C3.2, C7.2, C8.1, R3.1, R11.2, R12.1, U1.22 (VDDIO), U1.28 (VDD), U1.29 (EPAD), U2.5 (OUT)
+5V: J4.1, U2.1 (IN), U2.3 (EN)
GND: C1.1, C3.1, C4.2, C5.2, C6.2, C7.1, C8.2, D1.1 (K), J4.2, R10.1, U1.14 (VSSIO), U1.27 (VSS), U2.2 (GND)
unnamed: D1.2 (A), R12.2
unnamed: J1.1, R5.1
unnamed: J1.2, R6.1
unnamed: J1.3, R7.1
unnamed: J1.4, R8.1
unnamed: J1.5, R9.1
unnamed: J2.1, R4.2
unnamed: J3.1, U1.15 (ALARMB)
unnamed: J3.2, U1.16 (CSB)
unnamed: J3.3, U1.17 (SCLK)
unnamed: J3.4, U1.18 (SDI)
unnamed: J3.5, U1.19 (SDO)
unnamed: J3.6, U1.20 (DRDYB)
unnamed: R1.2, U1.8 (CMOUT)
unnamed: C4.1, U1.26 (CVREF)
unnamed: R5.2, U1.1 (IN1)
unnamed: R6.2, U1.2 (IN2)
unnamed: R7.2, U1.3 (IN3)
unnamed: R8.2, U1.4 (IN4)
unnamed: R9.2, U1.5 (IN5)
unnamed: C1.2, U1.11 (RLDIN), U1.12 (RLDREF)
unnamed: C2.1, R1.1, R2.2, U1.10 (RLDINV)
unnamed: C2.2, R2.1, U1.9 (RLDOUT)
unnamed: R4.1, U1.25 (RSTB)
unnamed: R3.2, U1.13 (SYNCB)
unnamed: R10.2, R11.1, U2.4 (RST/ADJ)
XTAL1: C6.1, U1.23 (XTAL1), Y1.1
XTAL2: C5.1, U1.24 (XTAL2), Y1.2

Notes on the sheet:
Crystal

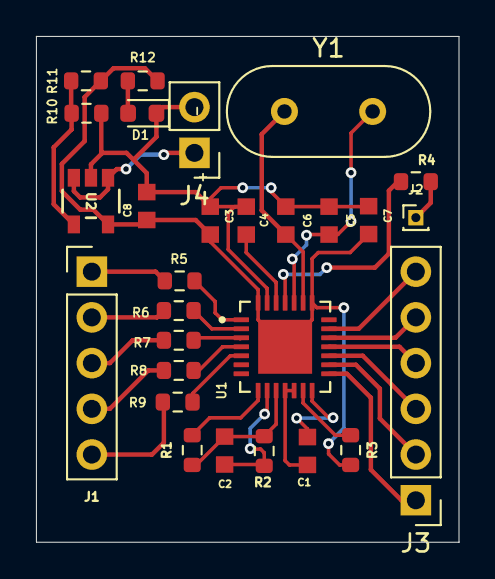
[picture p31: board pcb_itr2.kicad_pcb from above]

Board: 2 copper layers, 23.5 x 28.1 mm, 28 parts (0 on the bottom side), 31 nets.

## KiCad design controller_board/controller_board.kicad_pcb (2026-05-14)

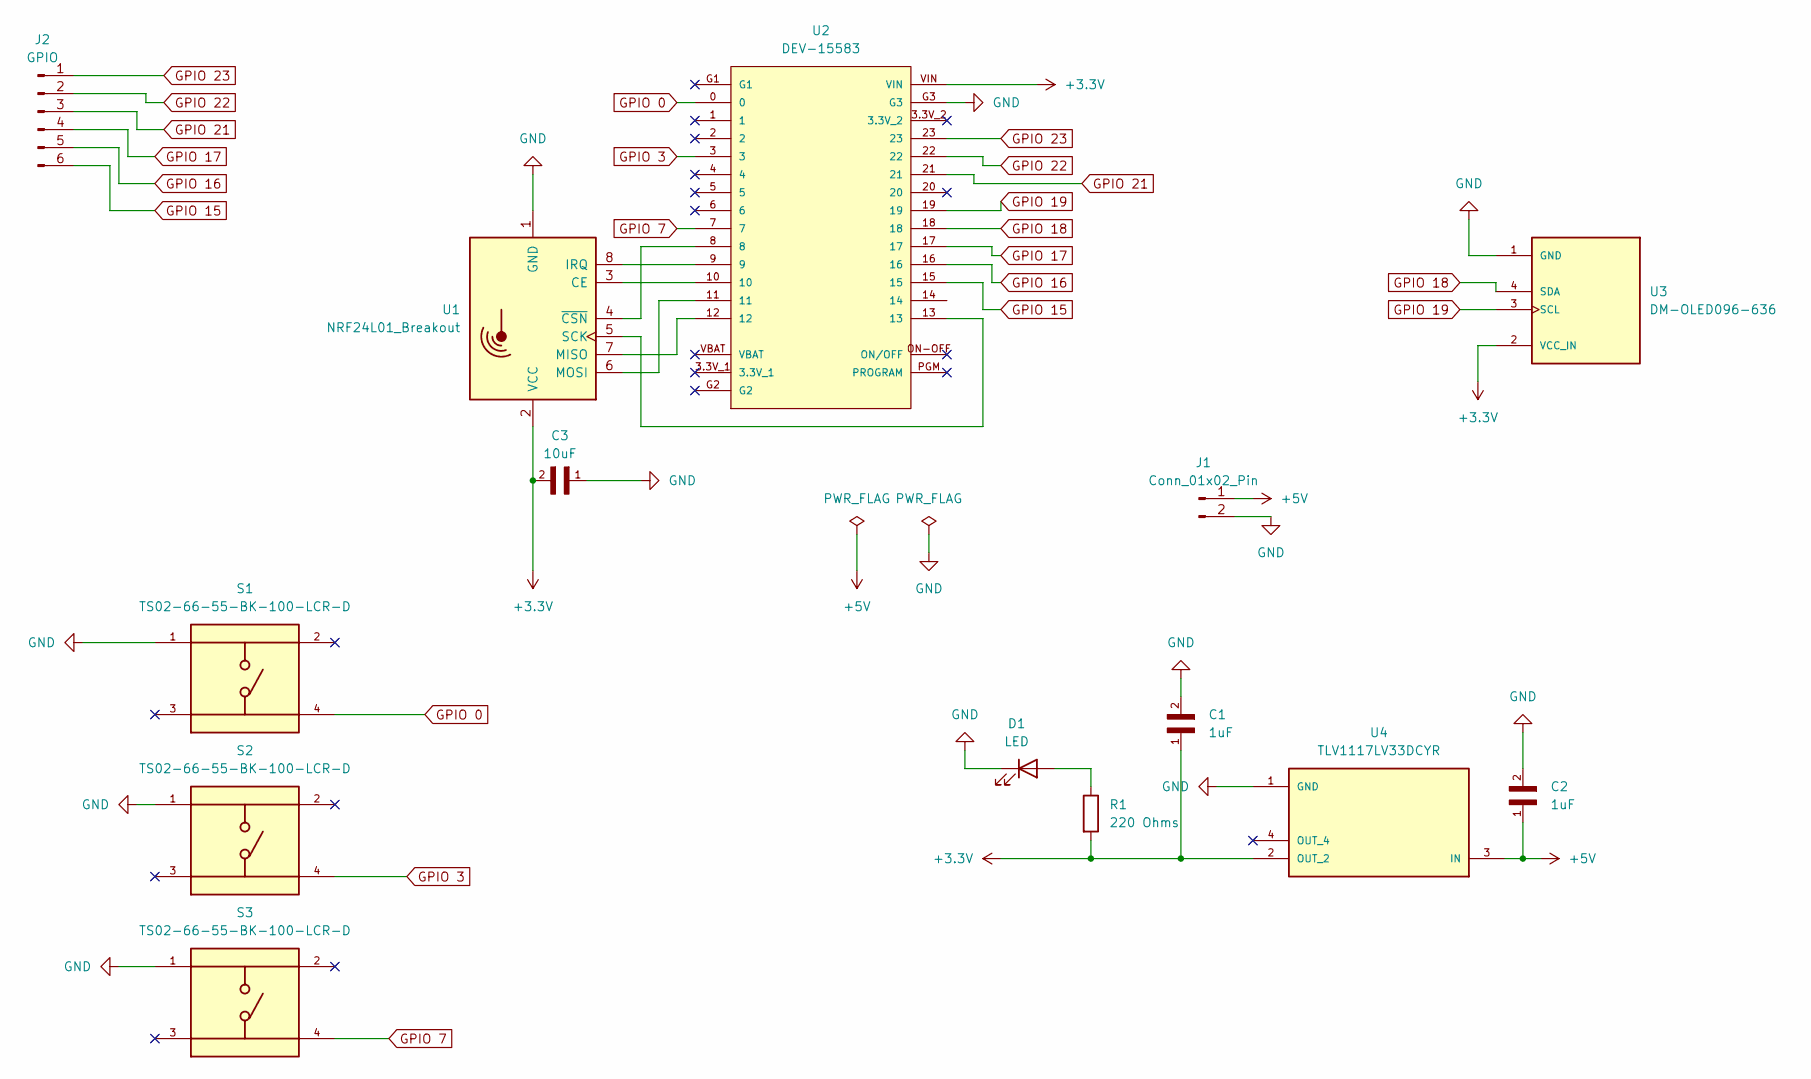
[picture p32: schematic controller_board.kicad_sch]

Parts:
C1, C2: 1uF; CAPC1608X87N
C3: 10uF; CAPC1608X87N
D1: LED; LED_0603_1608Metric_Pad1.05x0.95mm_HandSolder
J1: Conn_01x02_Pin; PinHeader_1x02_P2.54mm_Vertical
J2: GPIO; PinHeader_1x06_P2.54mm_Vertical
R1: 220 Ohms; R_0603_1608Metric_Pad0.98x0.95mm_HandSolder
S1, S2, S3: TS02-66-55-BK-100-LCR-D; SW_TS02-66-55-BK-100-LCR-D; PARTREV 1.0
U1: NRF24L01_Breakout; nRF24L01_Breakout
U2: DEV-15583; MODULE_DEV-15583
U3: DM-OLED096-636; MODULE_DM-OLED096-636; PARTREV 2018-09-10
U4: TLV1117LV33DCYR; VREG_TLV1117LV33DCYR; PARTREV B

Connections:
+3.3V: C1.1, C3.2, R1.2, U1.2 (VCC), U2.VIN, U3.2 (VCC_IN), U4.2 (OUT_2)
+5V: C2.1, J1.1, U4.3 (IN)
GND: C1.2, C2.2, C3.1, D1.1 (K), J1.2, S1.1, S2.1, S3.1, U1.1 (GND), U2.G3, U3.1 (GND), U4.1 (GND)
GPIO 0: S1.4, U2.0
GPIO 3: S2.4, U2.3
GPIO 7: S3.4, U2.7
GPIO 15: J2.6, U2.15
GPIO 16: J2.5, U2.16
GPIO 17: J2.4, U2.17
GPIO 18: U2.18, U3.4 (SDA)
GPIO 19: U2.19, U3.3 (SCL)
GPIO 21: J2.3, U2.21
GPIO 22: J2.2, U2.22
GPIO 23: J2.1, U2.23
unnamed: D1.2 (A), R1.1
unnamed: U1.3 (CE), U2.10
unnamed: U1.8 (IRQ), U2.9
unnamed: U1.7 (MISO), U2.12
unnamed: U1.6 (MOSI), U2.11
unnamed: U1.5 (SCK), U2.13
unnamed: U1.4 (~CSN), U2.8

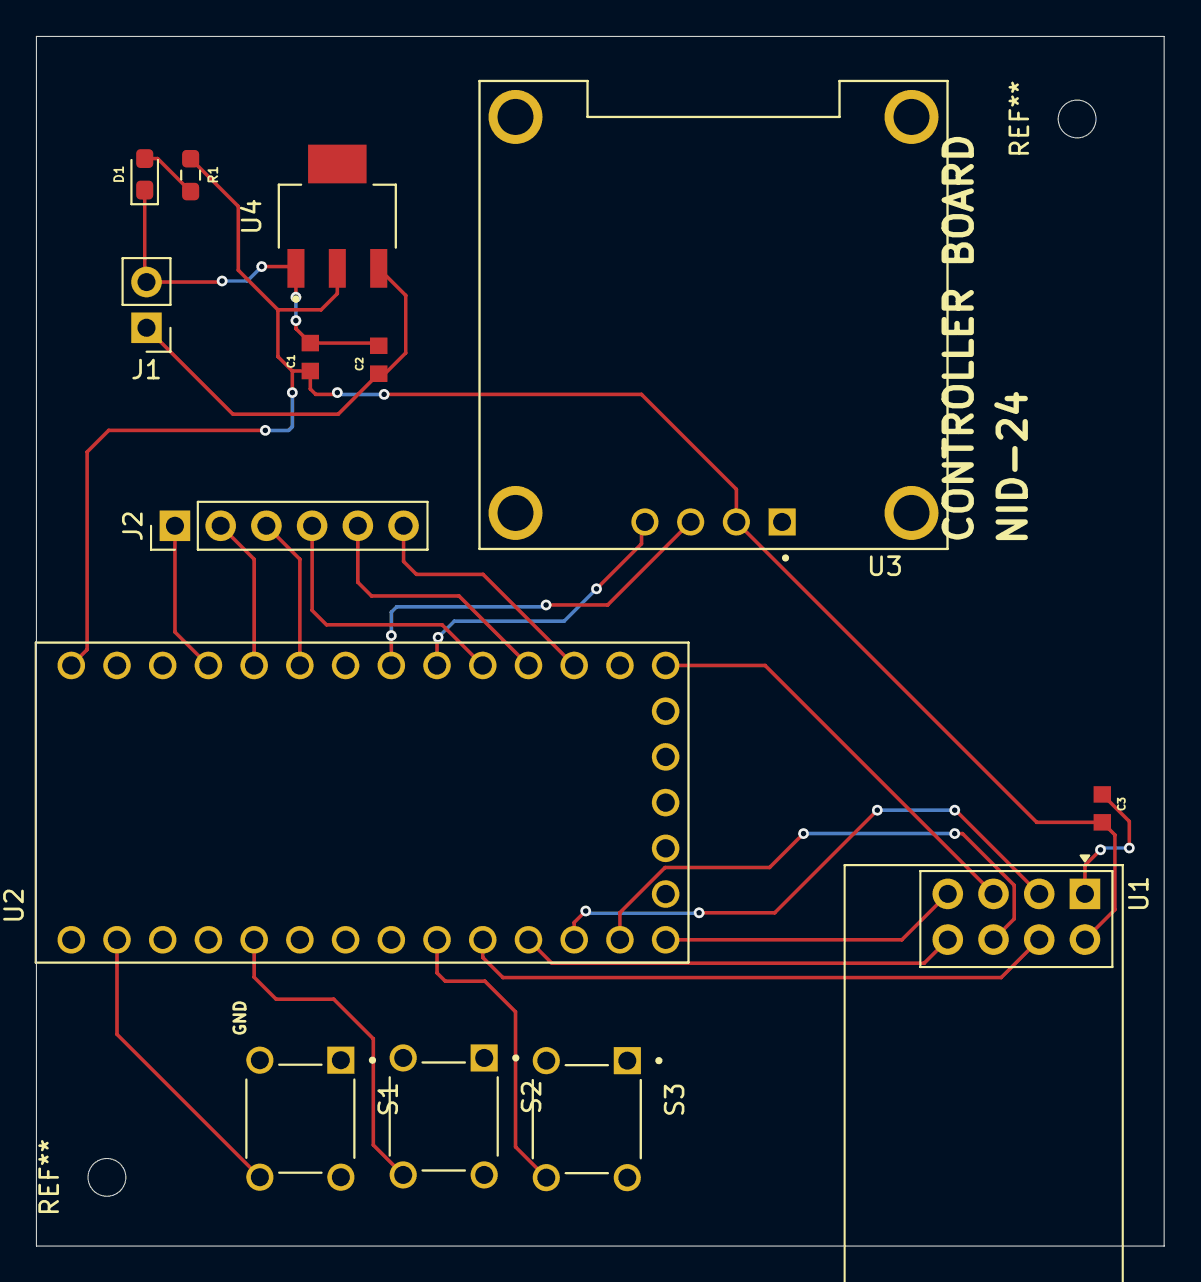
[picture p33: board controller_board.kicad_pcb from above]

Board: 2 copper layers, 62.7 x 67.2 mm, 14 parts (0 on the bottom side), 21 nets.

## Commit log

2026-04-04 regular update
    [ABLS-4.096MHZ-L4Q-T.step, CCS_CCSTD_0603_L1.75W0.95T0.87B0.35.step, DM-OLED096-636--3DModel-STEP-56544.STEP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]
2026-04-04 adding gerber files
    [controller_board-B_Cu.gbr, controller_board-B_Mask.gbr, controller_board-B_Paste.gbr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]
2026-04-06 added components link
    [BOM.csv]
2026-04-14 added synthetic emg signals generator
    [{10}.csv]
2026-04-19 Fixed toggle data btn
    [data.csv, {10}.csv]
2026-04-21 added a capacitor to nrf24l01 module
    [C0603C223J5RACTU.step, controller_board.kicad_sch]
2026-04-22 added total to BOM
    [BOM.csv, data.csv]
2026-04-25 added case
    [case.blend, case1.blend, controller_board.kicad_pcb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]
2026-04-25 update BOM
    [BOM.csv, pcb_itr2.kicad_sch]
2026-04-26 added case and new images of ADS1293 breakout board and controller board case
    [case 2.blend, controller_board.kicad_pcb, controller_board.kicad_sch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]
2026-04-27 fixed violation in ads1293 board due to accidental changes
    [pcb_itr2.kicad_pcb]
2026-04-27 restored BOM delete due to force push
    [BOM Final.csv]
2026-04-27 restored .step for ads1293 board
    [ads1293_board.step]
2026-04-28 improved data transmission
    [data.csv]
2026-04-28 added channel tabs and fixed recorder button ui logic
2026-04-30 improved directory structure
    [BOM.csv, case 2.blend, case.blend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]
2026-04-30 load features from features.txt
    [data.csv]
2026-05-01 added cuts to controller board case for airflow
2026-05-14 uploaded files for manufacturing
    [controller_board-B_Cu.gbr, controller_board-B_Mask.gbr, controller_board-B_Paste.gbr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]
2026-05-16 fixed resource unavailable
    [data.csv]
2026-05-20 fixed data toggle button styling
2026-05-30 compile dataset utility stable
    [dataset.csv]
2026-05-30 remove unwanted files
    [thumb_motion_raw.csv]
2026-06-05 more docs
    [pcb_itr2.kicad_pcb, pcb_itr2.kicad_sch]
